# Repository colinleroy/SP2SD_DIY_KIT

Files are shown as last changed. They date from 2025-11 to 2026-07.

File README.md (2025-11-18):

# Why this fork?

I recently bought an SPIISD v2 kit so that I could have a "hard drive" on my Apple //c.
My use-case is to be able to save documents, photos, programs to a large storage, because
floppies are... small.

Upon testing, I was disappointed to see that the SPIISD v2 works great, in conjunction with
ROM4x, when we boot the Apple //c from Smartport using the ROM4x menu, but that the drive
was "invisible" when booting from the internal floppy disk drive.

I was told this was a limitation of the Apple //c firmware, but could not believe it, as
it was documented nowhere on Internet, and people back in the day would have had a hard time
booting from an external hard disk drive without any means to initialize it.

This is when the second disappointment happened: I wanted to investigate the problem, but when
I bought the SPIISD v2, I missed the part in the documentation that says that the v2 firmware
is closed-source. I doubt the legality of this, given that it seems heavily based on the v1.17
firmware which is MIT-licensed, but that is not my main problem so far, as I so far had no
copyright on v1.17. I was mostly annoyed that I couldn't debug anything further than looking
at serial logs.

I traced the PCB connections from the IDC-20 Smartport connector to the Nano, and the ones
from the SD card module to the Nano, ignored the four buttons and the screen, and compared
those to the gerber files for the v1 board (those are [here](SPSD_DIY_NANO_GERBER)).
All connections matching, I flashed the v1.17 firmware on my v2 board, and started debugging.

So far, this repository fixes my problem: the SPIISD board was booting too slowly, and
missed the first Smartport RESET and ENABLE at cold boot, and so could not advertise its
existence to the Apple //c.

I solved it by reflashing the firmware using an AVR ISP mkII programmer, which bypasses the
Arduino's bootloader. As this was not enough, I defer slow inits to after having replied to the
computer.

# I have an official SPIISD and the same problem, how do I fix it

If you're here because you want your Apple IIc to see your SPIISD (v1 or v2) on cold boot,
here are your options:

- Hit Ctrl-Open-Apple-Reset one second after cold booting. This re-resets the Smartport bus,
but this time the SPIISD is booted.
- Power your SPIISD via an USB adapter, so that it's on before the //c
- Flash this firmware to your board, using a programmer instead of the USB connection, to
fix the root of the problem.

*Warning*: If you flash this firmware on an SPIISD v2 board, you will lose the screen and
buttons functionalities. If you flash this firmware on a v1 board, you will lose the "Eject"
button that is used to switch the SPIISD's bootable image.

In any case, backup your original firmware, using (via USB connection to the nano):
```
avrdude -c arduino -P /dev/ttyUSB0 -b 115200 -p m328p -U flash:r:SPIISD.orig.hex
```

If needed, you can restore it by first using the arduino IDE to reflash the bootloader:
- Tools / Board : Arduino Nano
- Tools / Processor : ATmega328P
- Tools / Programmer: AVR ISP mkII (or whatever your programmer is)
- Tools : Burn bootloader

Then reflash the firmware using your backup:
```
avrdude -c arduino -P /dev/ttyUSB0 -b 115200 -p m328p -U flash:w:SPIISD.orig.hex
```

# Directions for this project

I am not yet sure what I want to do with this project. I would like to have my
firmware conform to my needs (for example, I need only one or two partitions, and
I dislike seeing S2D1 and S2D2 when I won't use them). I would also like it to
be a good, solid Smartport hard drive implementation that would benefit the
community at large: while it is easy to find mass storage solutions for the
slotted Apple IIs, there are far less options to the //c, and as far as I know,
only one - the out-of-stock SPIISD v1 - is open-source.

So, if people are interested in such a project, I'm in. I am bad at hardware,
and while I can wire shit to the correct pins to make prototypes, I have zero
experience at making PCBs and each time I try to learn it's a nightmare. I'm
also bad at 3D printing and couldn't design and print an enclosure. But I'm
quite good at software.

So far, only huge nerds can use this firmware: it requires competency in Arduino
flashing *and* in what to do to transform gerber files into PCBs: the v1 board
is out of stock at Kero Mac Mods store, and the PCB is licensed under the CC-BY-NC-SA,
which prohibits others to step up, have some built and sell them to the community.
(Or, you could by a v2 board and use this firmware. Still, it's not as easy as
it should).

So what I would love to is to design a new PCB, MIT-licensed too, so that anyone
interested could build and sell them. Probably not me, I don't want to turn my
hobby into work.

Then I would like to fix/add features, maybe:
- fix the Eject button so that one can rotate their bootable image
- a jumper block to select 1, 2 or 4 partitions possible
- a clean-room implementation of a basic image selection UI

# SPIISD DIY KIT

<br>

# What is SPIISD ?
It is based on an open source project called SmartPortSD. 
Created by Australian genius [Robert Justice](https://web.archive.org/web/20230222233834/http://www.users.on.net/~rjustice/SmartportCFA/SmartportCFA.htm), SmartPortCFA was ported to Arduino hardware by Italian programmer genius [Andrea Ottaviani](https://github.com/aotta?fbclid=IwAR0_7cMKVhMVrHznB9bIub9ZmrmBlwAM3p6-_CQd0JFW1o736nUNZHyuTdw).  to porting to Arduino hardware. It was improved upon by [Katherine Stark](https://gitlab.com/nyankat/smartportsd) of Canada. She made available its ability to access four ProDOS-formatted 32MB PO files stored on a FAT32-formatted SD card. When she did this successfully, many wanted to build it.

*Got permission from the three geniuses I introduced earlier.<BR><BR>

We differentiated it with a name to distinguish it from other SmartportSD hardware (including unlicensed ones).<BR><BR>

<BR>
More details here (My Blog):
https://ameblo.jp/keroxiee1016/entry-12819341808.html

## Flashing Arduino Nano

Oct 15th, 2024: SmartportSD program has been updated to Ver.1.17, version 1.17 has been thoroughly tested with "SPIISD" hardware and has confirmed good performance. Fixed a problem with the Apple IIcPlus, and improved versatility with slower SD cards. Usage is the same as V.1.16.

May 8th, 2024: SmartportSD program has been updated to Ver.1.16 by Wing Yeung from [MFA2 work shop](http://www.mfa2lab.com). version 1.16 has been thoroughly tested with "SPIISD" hardware and has confirmed good performance. This same 1.16 program can work with both "SPIISD DIY KIT" and "SPIISD MINI". *We have not verified SmartportSD compatible devices from other manufacturers. I think they work well if they keep the same schematics.<BR>

- By placing "config.txt" at the root of the SD card, you can place various files without renaming them.<BR>
- Write 4x file names in "config.txt". SPIISD will only read files with that filename.
In addition to ".po", ".hdv" and ".2mg" can be used as extensions.<BR>
- Of course, you can put an unlimited number of images in the root of the SD card, but only the config.txt file will be read.<BR>
- If you do not place config.txt, you can also place four files from PART1.po as before.<BR>

You can flash your Arduino Nano via ArduinoIDE. Please download and use firmware of ["SmartportSD-1.17" folder](SmartportSD-1.17). If a new folder is created when using the Arduino IDE, please re-insert all the contents of this "SmartportSD-1.17" folder into the new folder. *The name of the ".ino" file should always be the same as the parent folder, so there is usually no problem if you use it as is.<BR>
<BR>
The Nano board you should choose is MEGA328P. Please do not buy MEGA168P as it has 38% insufficient capacity and cannot be flashed.<BR>
<BR>
The Arduino IDE settings are as follows,<BR>
Board: "Arduino Nano"<BR>
Processor: "ATmega328P(Old Bootloader)"<BR>
Port: Number of USB port connected to Arduino Nano *In your PC<BR>
Programmer: "AVRISP mkII"<BR>

## Assemble
Uploaded on Sep 24, assembly instructions can be found [here](SP2SD_DIY_INST.pdf), You can see which parts should be attached where by looking at our [BOM](SP2SD_NANO_DIY_BOM.csv). 
<BR>

<BR>
The IDC20 connector can be oriented in various ways depending on how you use it, When installing the male IDC20pin connector, be sure to make sure that the part is on the top side. When stacking two PCBs, make sure the hole and ▼ are in the same position. In that case, match the IDC20pin male and female connectors or connect them with a 2X10 pin header.<BR><BR>
日本語の組み立て説明書は[こちら](SP2SD_DIY_INST_JPN.pdf)から

## DB19 male connector

You can 3D print the base material and pull out the pins from a [DB25 male connector](https://www.amazon.com/PC-Accessories-Connectors-Connector-25-PACK/dp/B073KR622F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) and insert them, or purchase new pins from [AliExpress](https://www.aliexpress.com/item/1005002617586407.html?spm=a2g0o.order_list.order_list_main.16.55d11802jCHaOW). We have omitted unnecessary pins to make it simple for you to create. I will give out free .STL files that can be 3D printed. <BR><BR> DB19 connector file is [this](KEROS_DB19_V1.zip).

## 3D printed shell case

Our awesome friend [Mr Lurch](https://www.youtube.com/channel/UCMQ28v823w6p1ZnyiZDVwUg) completed the shell case design. This can be used by connecting boards A and B with pin headers without using cables.<BR><BR>
 [Here](https://www.thingiverse.com/thing:6235981) is the case stl files for integrated.<BR>
 [Here](https://www.thingiverse.com/thing:6248598) is the case stl files for cable connection.




## Supported Apple II computers

<BR>


<BR><BR>
- Apple IIgs　*Even you set the startup slot to #5 and remove other bootable devices the startup timing does not match, try the shortcut key "Open Apple" + "Control" + "Reset" to reboot. If you are new to IIgs, make sure to release key "Open Apple"　 last and it will reboot easily.<BR>
- Apple IIc, IIc Plus *In the case of IIc, Smartport cannot be used as is with older ROM 255, so a ROM upgrade is required. See the chapter bellow
- Apple IIe, IIe Enhanced, IIe Platinum, works well with Grappler Minus card (1) with SoftSP diy ROM V2, V3 and V6-a. It works into the #5 slot and use it via the DiskII card in the #6 slot. In other words, it is a card that connects SmartPort with two cards.<BR>*You can also use it via "Liron" card, BMOW also has a highly functional card called "Yellowstone", which can also be used. <BR>
- Apple II Plus, works well with GrapplerMinus card with SoftSP diy ROM V2, V3 and V6-a.<BR>

(1) We developed the [Grappler Minus card](https://github.com/kerokero5150/GrapplerMinus/blob/main/README.md), which overcomes timing issues. This is also open source and anyone can create it, but it is not allowed to be sold. It is also available for purchase at our store. <BR><BR>
If you use SoftSP with the Genuine "Grappler Plus" card, the functionality of SoftSP DIY will be limited due to the unnecessary circuitry of the printer interface. Specifically, it only works with Apple IIe, and only V2 and V3 ROMs can be used.

## Usage
<BR>
Use a FAT32(16) formatted MicroSD card. Most of the MicroSD cards currently on sale can be used as is.
Extension .po files can be used.<BR><BR>

### Usage V.1.17(1.16)
New firmware allows the use of three file extensions: ".po", ".hdv", ".2mg", each files with a maximum size of 32MB.
As we have upgraded to V.1.17(1.16), the new method for setting up the SD card is described below. From v1.16 onwards, if "config.txt" is not placed in the root, it will be automatically recognized and converted to the old method. Please refer to “2, Old method” when "config.txt" is not placed.＜BR>
Place "config.txt" in the root of the SD card, this is a standard text document, which can be created using any text editors. This is the table of contents for loading the specified file into the Apple II. The contents of "config.txt" must have a file name written on each line, and you can specify up to four files to launch. You can add as many files as you like up to the capacity of the SD card. However, SPIISD can only read the four files with the names written in config.txt. The file extensions are either ".po", ".hdv", or ".2mg". SPIISD will read from the first file written (on the first line). Please keep in mind that the file specification must always be 4 lines for 4files.

### Usage up to V.1.15<BR>
The Apple ProDOS disk image that can be used for SPIISD is a .PO file with a maximum size of 32MB. Place this file at the root of your micro SD card. Up to 4 files can be recognized. The first file name should be “PART1.PO”. As you can imagine, there can place four files, so from the second file on, name the files with regularity, such as "PART2.PO", "PART3.PO", and "PART4.PO".<BR>
For disk images with the .hdv extension, the catalog structure is the same, so you should be able to use them by simply renaming the file to .po. An APP called CiderPressV4 can convert other file extensions to .po.<BR><BR>
I think the most popular way to use SPIISD on the IIc is to use TotalReplay, a collection of old appleII games. <BR>
The IIgs supports GSOS. In this case, you can check all four files at the same time on the OS's finder. If you only have a IIgs, the SPIISD is the device with the best value for money.<BR><BR>
*If you change the extension from .hdv to .po and it doesn't work, you can use CiderPress to convert it to a .PO file. CiderPressV4 can be done on Windows 7 and up. *For Win98/ME/2K/XP there is an older version.<BR>
<BR>
CiderPress V4:<BR>(https://a2ciderpress.com)<BR><BR>
TotalReplay:<BR>(https://archive.org/details/TotalReplay)<BR><BR>

## To use Apple IIc's smart port
For Apple IIc, Smartport will not be enabled if ROM 255 is installed(Probably ROM0 as well). To check the ROM of your IIc, run the following program from the Basic prompt.
  PRINT PEEK (64447)
If the output number is "255", the ROM needs to be replaced. The ROM versions that Smartport can use are "3", "4" and ROM"4x". For these numbers, ROM replacement is not necessary.

The replaced ROMs are available [here](https://mirrors.apple2.org.za/Apple%20II%20Documentation%20Project/Computers/Apple%20II/Apple%20IIc/ROM%20Images/).
There is also the useful hacked [ROM4X](https://github.com/mgcaret/rom4x). This is a fairly new ROM updated in 2018.<BR><BR>

My recommendation is ROM4X.<BR>

If you want to swap the ROM from 255 to another ROM, you need to change the solder jumpers "W1" and "W2". 
255 is 16KB while other ROMs are 32KB. Enable 32KB by changing Pin27, which is A14, from pull-down to pull-up. 
See below for solder jumper locations. [External site](https://www.apple2faq.com/apple2faq/apple-iic-rom-upgrade/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)

## To get the SPIISD PCB

You can use [SPSD_DIY_NANO_GERBER.zip](SPSD_DIY_NANO_GERBER.zip)  and uploading it to JLCPCB or PCBWAY as it is.

<BR>


The [SPIISD DIY kit](https://en.infinityproducts.co.jp/product-page/sp2sd-diykit-bare-pcb-board-a-b) comes complete with all parts, sold in our [store](https://en.infinityproducts.co.jp/shop-1). [SPIISD mini](https://en.infinityproducts.co.jp/product-page/spiisd-mini-for-iic-iicplus-iigs) is a compact hardware with fixed db19. It does not require assembly, so it is recommended for those who want to use it immediately, and for those who want a sense of unity with Apple IIc.

## Licenses

SmartportSD software licenses are listed [here](SMARTPORTSD_LICENSE.md) under the MIT license.
Ⓒ2023 Katherine Stark, Robert Justice, Andrea Ottaviani. All rights reserved.

This SPIISD hardware is licensed under a
[Creative Commons Attribution-ShareAlike 4.0 International License](https://creativecommons.org/licenses/by-nc-sa/4.0/).
Ⓒ 2023 Kay Koba, Kero's mac Mods, All rights reserved.


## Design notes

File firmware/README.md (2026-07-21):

# Programming the Arduino Nano with BurgerDisk's firmware

In order for the Arduino Nano to boot fast enough to answer an Apple //c booting
from its internal floppy, the Nano **has** to be programmed using an AVR ISP
programmer. I use an [STK500 AVR ISP programmer](https://aliexpress.com/item/1005006205386137.html).

Open a terminal, and change to this `firmware/` directory.

## Arduino IDE installation
Install the Arduino IDE, for example on a Debian-based Linux distribution:
```
sudo apt install arduino
```

Start it:
```
arduino .
```

## Arduino IDE configuration
The Arduino IDE Tools menu.

In `Tools` menu, `Programmer` submenu, select your programmer.

You can then either continue using the Arduino IDE interactively:
- In `Tools` menu, `Board` submenu, select `Arduino Nano`.
- In `Tools` menu, `Processor` submenu, select `Atmega328p`.
- In `Sketch` menu, `Include Library` submenu, select `Manage Libraries...`.
  Manage Libraries menu item.
- Search for `SdFat` by Bill Greiman, scroll to it, and install version 2.3.0 (Screenshot shows 2.1.2, but choose 2.3.0).
  SdFat installation

Or, you can quit the Arduino IDE, and in your terminal, run:
```
make setup
```

## Flashing the firmware
**Make sure that the Nano is out of the BurgerDisk PCB, or that the BurgerDisk
is disconnected from the Apple II, even if the Apple II is turned off, before connecting the programmer. NEVER connect the programmer when the BurgerDisk is
connected to the Apple II.**

Connect your Arduino Nano to the programmer's 6-pin connector. The red
wire of the connector must be towards the Nano's `VIN` pin.
The Arduino Nano, connected to the programmer

For the Dominodisk, the procedure is the same. Open the Dominodisk enclosure to
locate the programming header, and connect it:
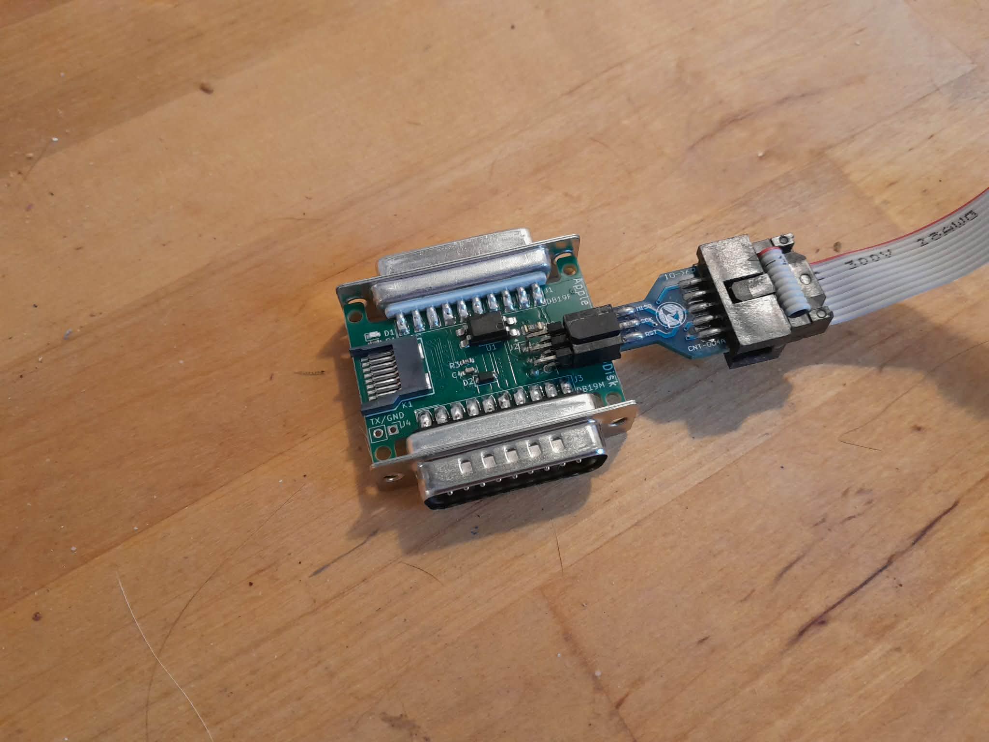
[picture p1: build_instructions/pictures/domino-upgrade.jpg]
The Dominodisk, connected to the programmer


Two options here too:
- From the Arduino IDE, `Sketch` menu, choose `Upload using programmer`. Wait
  until the "Done uploading" message.
  Upload using programmer menu item
- From the command line, run `make fuse && make upload`. Wait for the upload to be done.

Disconnect the programmer, and you're set.

## Debugging
If you need to debug the firmware, you can connect its UART pins to an [UART/USB
converter](https://aliexpress.com/item/1005008293602159.html). Wire the
BurgerDisk's UART `GND` pin to the USB converter `GND` pin, and the BurgerDisk's
UART `TX` pin to the USB converter's `RX` pin.

Plug the USB converter in your computer, check its device file (using `dmesg`
for example), then run:
```
minicom -D /dev/ttyUSB0 -8 -b230400
```

Connect the BurgerDisk to the Apple II, and boot the Apple II. Log messages
should be visible in Minicom. Remember: **never have the programmer connected
while the PCB is connected to an Apple II!**

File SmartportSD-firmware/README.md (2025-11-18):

# SmartportSD FAT version 1.17

This is an enhancement of the [SmartportCFA/SmartportSD](http://www.users.on.net/~rjustice/SmartportCFA/SmartportCFA.htm) project by Robert Justice and Andrea Ottaviani. Instead of relying on four raw disk images written sequentially to an SD card, this version allows you to have up to four files on a FAT or FAT32 formatted SD card instead.

version 1.17: Improved version by Wing Yeung from [MFA2 work shop](http://www.mfa2lab.com). version 1.16 has been thoroughly tested with "SPIISD" hardware and has confirmed good performance.This same 1.16 program can work with both "SPIISD DIY KIT" and "SPIISD MINI". V1.17 adds support for IIcPlus. Memory allocation has been changed to dynamic allocation.

*We have not verified SmartportSD compatible devices from other manufacturers. I think they work well if they keep the same schematics.

# Usage

## Get the programs

Download or git clone the source to this project. Copy and use the "SmartportSD-firmware" folder as is.

## Get the dependencies

Download the 2.1.2 version of the [SdFat Arduino library](https://github.com/greiman/SdFat/) and install it in your Arduino libraries folder (that location is system-dependent so you'll have to figure out where it is for you, sorry).

## Compile and upload the code to the Arduino

## Wire up the Arduino

Follow the instructions on [Robert's page](http://www.users.on.net/~rjustice/SmartportCFA/SmartportSD.htm) for the wiring diagram.

### WARNING

Don't connect the Arduino USB and the +5V power to the Apple computer at the same time! Doing so could lead to a situation where +5V is backfeeding into the Apple from the Arduino, which is bad.

If you plan on doing development work on this, or just want to watch the Arduino serial console for error messages, disconnect the +5V connection between the Apple II and the Arduino and power it only via the USB port.

If you use the v1 or v2 PCBs from Kero Mac Mods, there is a diode preventing this
from happening, so it's possible in this case.

#### Technical details
The Apple needs more than the 500mA your modern computer's USB power supply can provide to boot up, plus it needs some other voltages as well. You could end up burning out your Arduino, your USB port, your Apple, or all of the above! (The most likely thing to happen is the USB port might shut off, or the Arduino will get hot and annoyed, though).

## Place images on the SD card

You can place unlimited images in the root or subfolders of the SD card. However, only the four files specified in config.txt can be mounted.
By placing "config.txt" at the root of the SD card, you can place various files without renaming them.
Write 4x file names in "config.txt". SPIISD will only read files with that filename.
In addition to ".po", ".hdv" and ".2mg" can be used as extensions.
If config.txt is not in the root, Name your images PART1.PO through PART4.PO. If you don't have four images that's OK, the missing ones will be skipped.

### NOTE

Images must be unadorned ProDOS-order images. They don't have to be ProDOS file systems though - ISO9660, DOS 3.3 and HFS should work (although they are currently untested).

## Change boot  order, if you want

The eject button, if you have it wired up, will work the same way as it does in Robert's version of the code. Hold the button down while power cycling the Apple (or pressing the Arduino reset button if the USB connection is supplying power) to choose the next of the four images as the new startup disk. Then power cycle (or reset) the Arduino again without the button held down to get ready for the next boot.

### WARNING

Make sure you have a pulldown resistor to ground on the eject button pin (Analog pin 3). If you don't, the Arduino will assume the button is always being held down and keep changing the boot device and never start its normal operation. Ask me how much debugging trouble this caused me!

## Boot the machine!

That's it, turn on the machine and it should boot from PART1.PO!

## BUGS

- The combination of this device, a ROM 03 IIgs, and a CFFA3000 card seems to  prevent booting from this device. If you have this setup, please test it and report back to me.
- The code for switching boot partitions is probably going to fail if files get renamed so that a previously present boot partition goes away.

Please report bugs or comment on the above via the GitLab issues page for the project.

April 27, 2024, Ver 1.16 edited by Kay Koba, Kero's Mac Mods

(C) SmartportSD Project

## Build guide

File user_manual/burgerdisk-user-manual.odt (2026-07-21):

BurgerDisk/DominoDisk Smartport Hard Disk for Apple II

User manual

Version 2.5

April 2026

colin@colino.net – https://www.colino.net/

# Index of Figures

Figure 1: Inserting the MicroSD card 5

Figure 2: Example daisy-chain 6

# Index of Tables

Table 1: Example config.txt 4

# Introduction

BurgerDisk and DominoDisk are Smartport hard disks, with storage backed on a microSD card, for the Apple II line of computers running ProDOS.

Both devices share the same firmware and the same features, so this user manual applies equally to both devices.

It is compatible with the Smartport-enabled Apple II models:

- The Apple //c (apart from the ROM255 version, which can be upgraded)
- The Apple IIgs
- Slotted Apple II computers with a Smartport controller:
  - DiskII controller + a SoftSP card, or
  - Liron card, or
  - Liron Reborn card

It is daisy-chainable, which lets you use other storage devices with it.

# BurgerDisk storage configuration

## Presenting disk images to the computer

Different image formats are supported:

- .po (in ProDOS-ordered format)
- .2mg (in ProDOS-ordered format)
- .dsk (in ProDOS or DOS3.3-ordered format, but of ProDOS volumes)
- .hdv

These images can be either 140KB, 400KB, 800KB, or an arbitrary number of blocks up to 32MB (65535 blocks).

The BurgerDisk does not support .woz, .nib, .edf, .do images.

BurgerDisk uses these disk images to present to ProDOS. They are stored as files on the MicroSD card, formatted as FAT.

By default, the firmware will search for four files: PART1.po, PART2.po, PART3.po, PART4.po, and present them if they exist.

You can also put images with arbitrary names, and reference at most four of them in the config.txt file at the root of the MicroSD’s filesystem.

Table 1: Example config.txt

A2DeskTop-1.5-en_800k.2mg

Total Replay v5.2.hdv

Documents.po

Your Apple II can boot from any slot, but only from the first device in any slot. For the BurgerDisk, this means you can boot from the BurgerDisk’s first volume if the device is first in the daisy-chain. Booting from another partition requires modifying their order in config.txt.

Afterwards, you can insert the MicroSD card in its slot (face up, connector down), connect your device to your Apple II, and boot it.

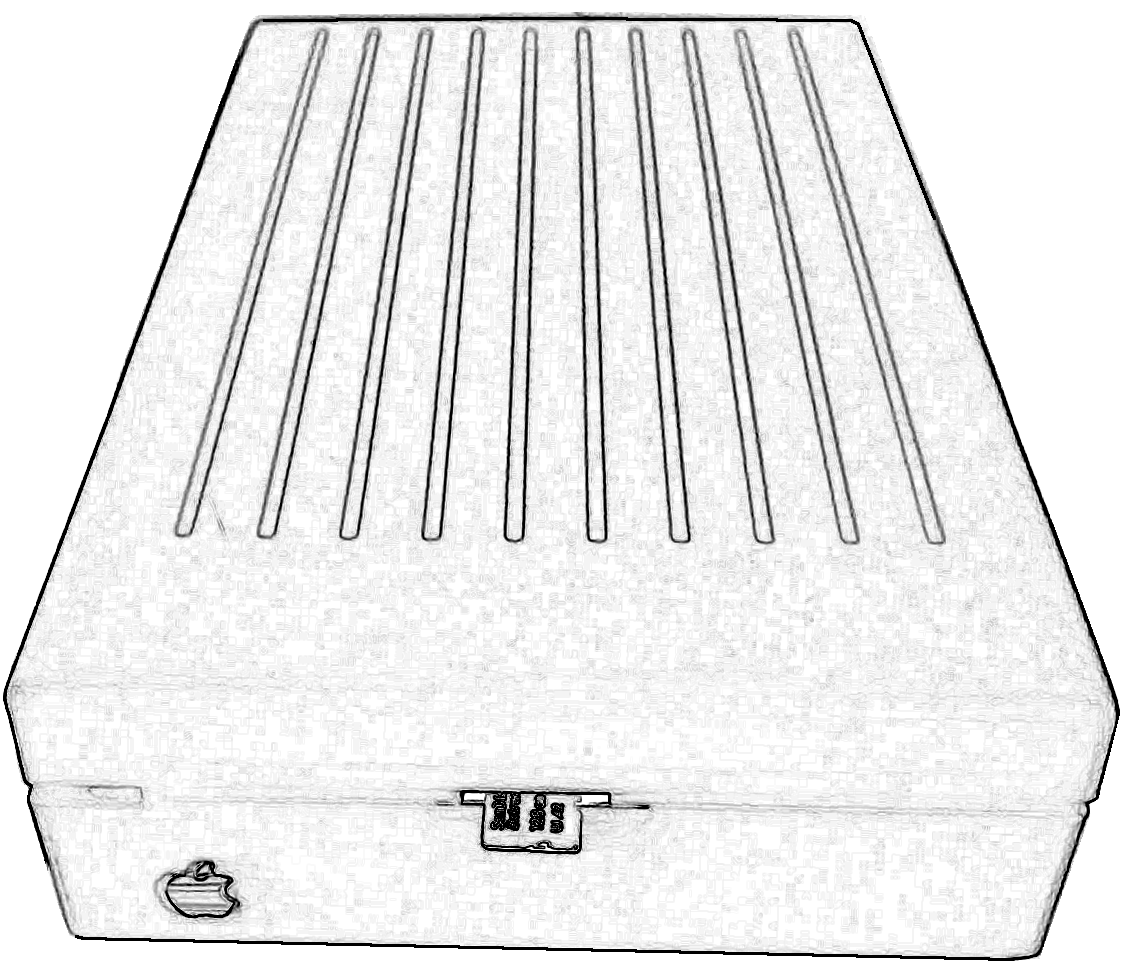
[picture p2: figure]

Figure 1: Inserting the MicroSD card

Push the card until it clicks in place. Push it again to remove it.

## Debugging and options

debug (default 0): If you would like to work on the BurgerDisk firmware, enabling debug messages on its serial port will be useful. You can do that by adding debug=1 in an options.txt file at the root of the SD card.

force_next_smartport (default 1): By default, BurgerDisk lies to the controller, telling it there are more Smartport devices after it. This makes chaining an SPIISD (or other devices that do not correctly advertise themselves as Smartport devices) possible. It has no adverse effects, but this can be disabled using force_next_smartport=0 in the options.txt file.

# BurgerDisk installation

To connect the BurgerDisk to your Apple II, you can either plug it directly to the computer, or to another device, in what is called a Daisy Chain. This allows you to have multiple storage devices connected to your computer. Daisy chains have rules about devices ordering:

- First “dumb” 3.5” floppy drives, like the Apple 3.5 Drive (A9M0106) (only on the IIgs or //c+)

- then Smartport devices, like the Unidisk 3.5 (A2M2053) or the BurgerDisk

- followed by 5.25” floppy drives (except on Liron cards, which do not handle 5.25” drives at all)

In this example, the Apple II will be able to boot from the Unidisk 3.5”. To boot from the BurgerDisk’s first partition, invert the Unidisk 3.5” and BurgerDisk, so that the BurgerDisk is connected to the computer, the Unidisk connected to the BurgerDisk, and the Disk //c connected to the Unidisk.

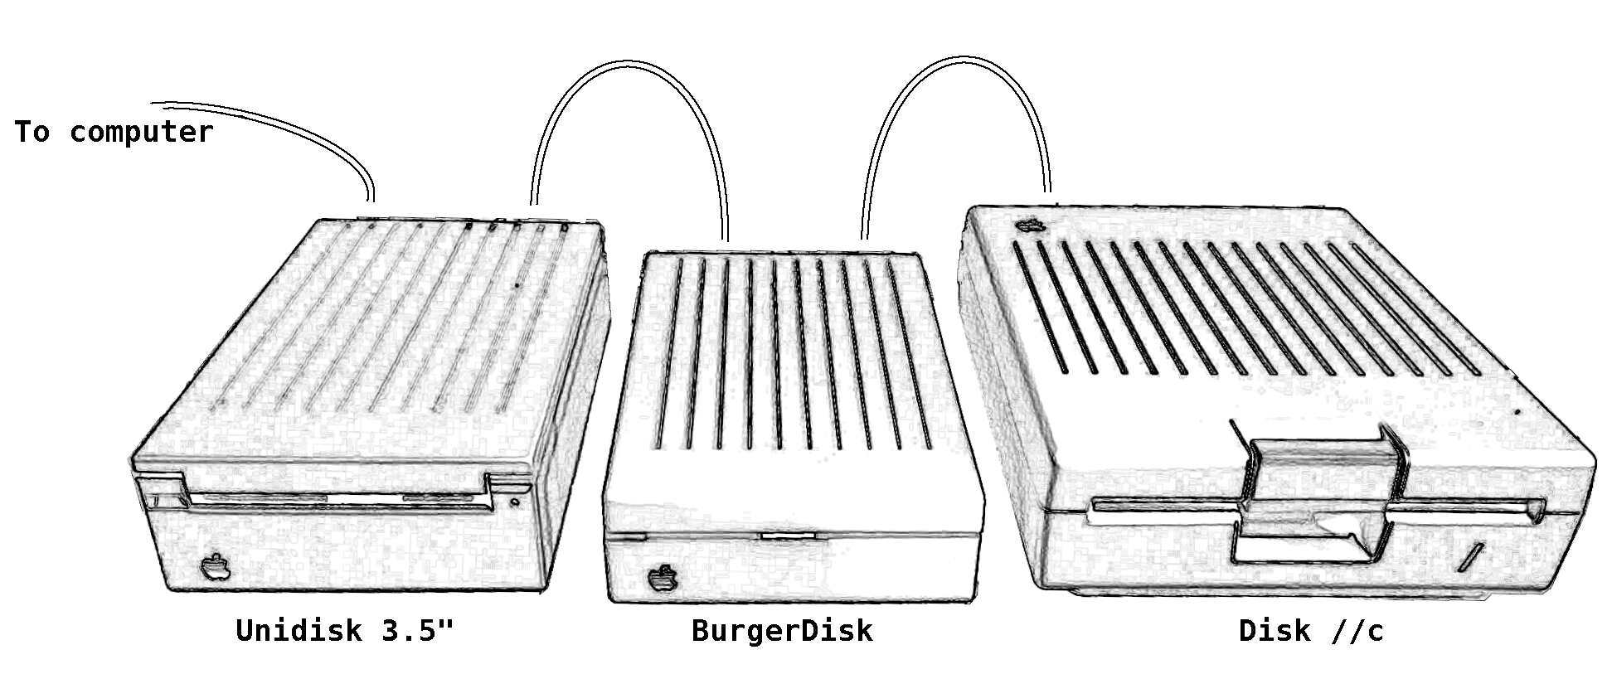
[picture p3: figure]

Figure 2: Example daisy-chain

# Booting the computer

The Apple II can boot from the first device in a given slot. Smartport devices are usually in slot #5, and 5.25” drives in slot #6.

If you want to boot your Apple II from the BurgerDisk, use a bootable image, like A2Desktop, as first image; and connect the BurgerDisk first to the computer.

Note: this means that you cannot directly boot from the BurgerDisk if an Apple 3.5” drive (A9M0106) is present in your chain, even if no floppy is inserted into it; because the A9M0106 drive has to be connected first.

# Troubleshooting

## Serial debug output

If you are investigating a problem or experimenting with your own modifications of the firmware, you might want to enable debug output on the Arduino’s serial port.

This can be enabled with a debug=1 line in options.txt.

Afterwards, you can open the enclosure, locate the UART port, and connect an UART to USB adapter to it. Connect the UART’s GND to the adapter’s GND, and the UART’s TX to the adapter’s RX.

## Blinking LED, no image mounted

If after booting the Apple II, a small delay happens, followed by the BurgerDisk’s LED blinking 4 times per second, and none of its volumes are visible by ProDOS, this means that the MicroSD card initialization failed, or that zero valid images were found on the card. Verify its presence and contents.

## Compatibility

So far, the BurgerDisk has been tested on:

- Apple //c ROM3, model A2S4000
- Apple //c ROM4x, model A2S4100
- Apple IIgs, ROM01
- Apple IIe, Liron card
- Apple IIe, DiskII controller + SoftSP card

Various daisy chaining configurations have been tested:

- only the BurgerDisk on the Smartport bus
- Unidisk 3.5”, then BurgerDisk
- BurgerDisk, then Disk //c
- Unidisk 3.5”, then BurgerDisk, then Disk //c
- Unidisk 3.5”, then BurgerDisk, then another BurgerDisk, then Disk //c
- BurgerDisk, then Unidisk 3.5”, then Disk //c

In case of problems in a daisy chain, verify that your chain respects Apple’s rules, and that the chained devices are actually able to be chained.

Liron card notes: the Liron card is not able to drive a 5.25” drive.

SoftSP card notes: the SoftSP card is not able to drive a Unidisk 3.5” drive. It has annoying, but non-blocking issues with 5.25” drives.

Compatibility with the SPIISD, Fujinet, or other Smartport-based devices has not yet been tested.

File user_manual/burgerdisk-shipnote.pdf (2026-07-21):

## BurgerDisk Smartport Hard Disk for Apple II

## Quickstart

Thank you for getting a BurgerDisk! I hope you will like it.

The User Manual is available at https://www.colino.net/wordpress/wp-content/burgerdisk-usermanual.pdf (https://www.colino.net/wordpress/wp-content/burgerdisk-user-manual.pdf)

Here are the most relevant parts:
Insert a FAT-formatted microSD card in the slot, face up. The volumes presented to the Apple II must be named PART1.po to PART4.po, or be referenced in a config.txt file containing up to four lines with the filenames. For example:
A2Desktop.hdv
Total_Replay.hdv
ProDOS 2.4.3.po

Do not hotplug Apple II storage devices while the Apple II is powered on. Plug any “dumb” 3.5inch drive first, followed by the DominoDisk and Smartport devices, followed by 5.25” drives.

Your enclosure comes with a placeholder logo taped at the front. You can either glue it, or replace it with a real vintage Apple logo if you have one!
Have fun,
Colin
colin@colino.net

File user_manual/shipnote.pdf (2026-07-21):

## BurgerDisk Smartport Hard Disk for Apple II

## Quickstart

Thank you for getting a BurgerDisk! I hope you will like it.

Quick pointers to start using it:

The User Manual is available at https://www.colino.net/wordpress/wp-content/burgerdisk-user-manual.pdf (https://www.colino.net/wordpress/wp-content/burgerdisk-user-manual.pdf)

Assembly instructions are available at https://github.com/colinleroy/BurgerDisk/tree/main/build_ins tructions (https://github.com/colinleroy/BurgerDisk/tree/main/build_instructions)

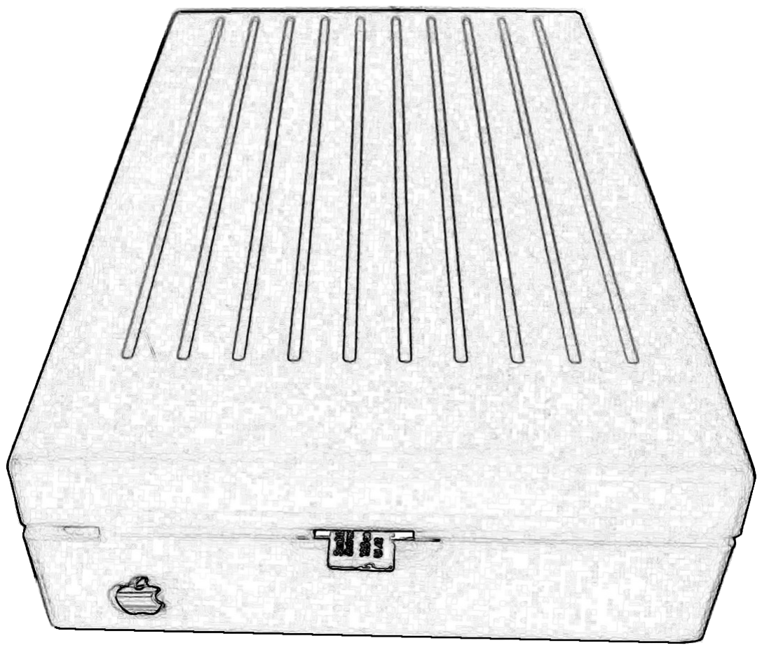
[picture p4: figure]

Your enclosure comes with a 3D-printed Apple logo taped to it. You can either glue it, or remove it and glue a real vintage Apple logo if you have one available.
Have fun!

Kit contents
Small components taped here

R2
150Ω

R1
330Ω

D1
removed

D2
1N4448

D3
1N5818

R4
10kΩ

R5
1kΩ

R3
470Ω

E

r

r

a

t

a: D1 w

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
d. In the box, for the PCB
- One BurgerDisk PCB
- One adapter PCB
- One Arduino Nano
- One MicroSD module
- One pair of DB19 connectors
- One pair of IDC20 connectors
- One pair of 15-pin sockets
- One LED
- One PC817 optocoupler
- Two 2-pin headers
- One 6-pin header
- One 6-pin cable
- One 2-pin cable
- One IDC20 cable
- 2 M2x8mm screws

In the box, for the enclosure
- The enclosure itself
- The adapter’s enclosure
- One LED diffuser
- One white Apple logo
- Two M2x12mm screws
- Four M3x20mm screws

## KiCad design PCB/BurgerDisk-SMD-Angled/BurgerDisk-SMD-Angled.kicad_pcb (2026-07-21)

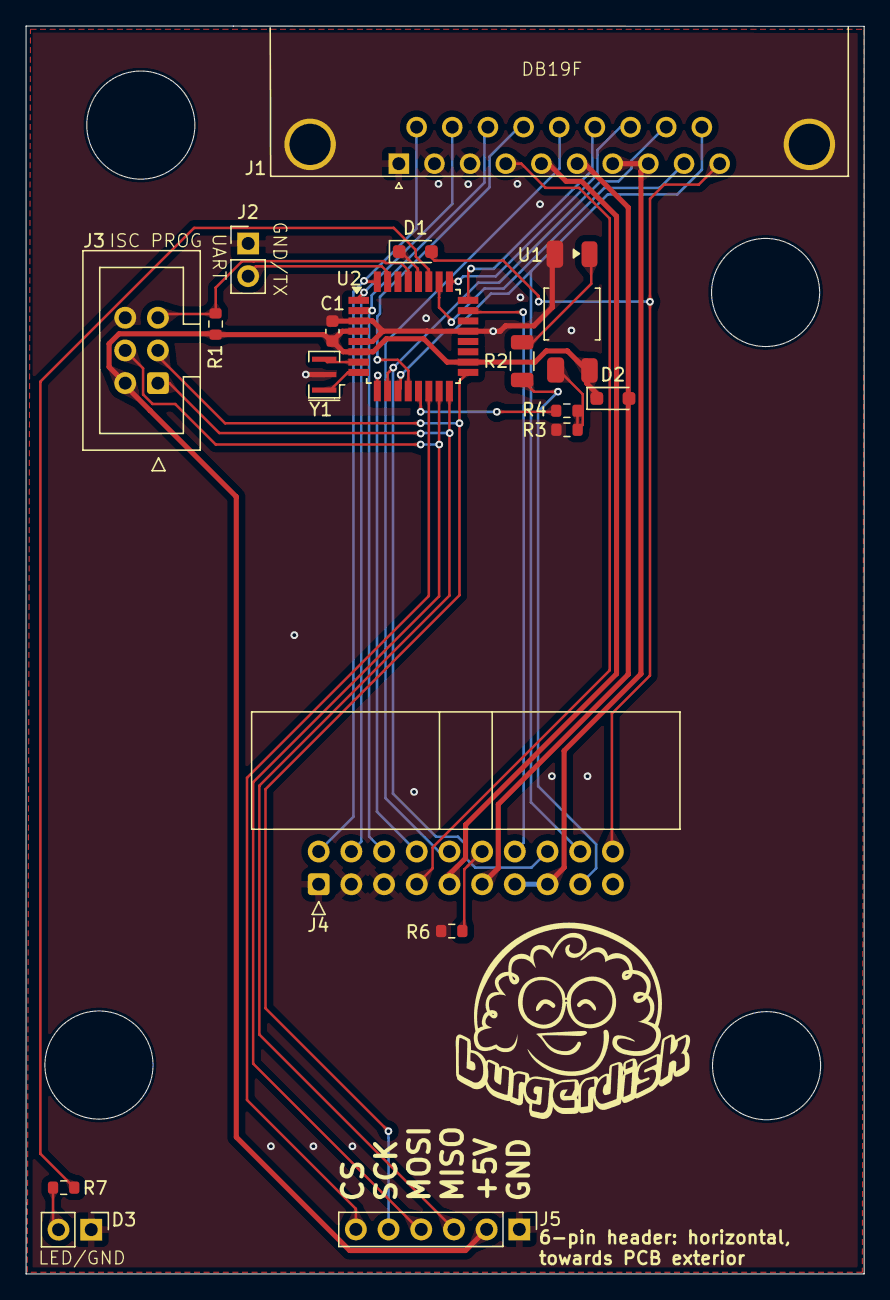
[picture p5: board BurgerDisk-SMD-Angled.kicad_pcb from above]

Board: 2 copper layers, 65.1 x 96.9 mm, 18 parts (0 on the bottom side), 35 nets.

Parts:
C1: 100n; C_0603_1608Metric
D1: 1N4448WS; D_SOD-323_HandSoldering
D2: 1N5818WS; D_SOD-323_HandSoldering
D3: LED; PinHeader_1x02_P2.54mm_Vertical
J1: Daisy port out; DSUB-19_Female_Horizontal_MXS82009-8251-9246
J2: 2-pin header; PinHeader_1x02_P2.54mm_Vertical
J3: ICSP_ISP6; IDC-Header_2x03_P2.54mm_Vertical
J4: Daisy port in; IDC-Header_2x10_P2.54mm_Horizontal
J5: MicroSD module; PinHeader_1x06_P2.54mm_Vertical
R1: 10K; R_0603_1608Metric
R2: 470; R_1206_3216Metric
R3: 10k; R_0603_1608Metric
R4: 1k; R_0603_1608Metric
R6: 330; R_0603_1608Metric
R7: 150; R_0603_1608Metric
U1: PC817C-S; SOP-4_3.8x4.1mm_P2.54mm
U2: ATmega328P-AU; TQFP-32_7x7mm_P0.8mm
Y1: Resonator_GND2; Resonator_SMD_Murata_CSTxExxV-3Pin_3.0x1.1mm

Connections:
5V_apple2: D2.2 (A), J1.6, J4.11
5V_burgerDisk: C1.1, D2.1 (K), J3.2, J5.2, R1.1, U1.4, U2.4 (VCC), U2.6 (VCC), U2.18 (AVCC)
+12V: J1.7, J1.8, J4.13, J4.15
-12V: J1.5, J4.9
CS: J5.6, U2.14 (PB2)
DRV1_in: J4.14, U2.23 (PC0)
DRV1_out: J1.17, U2.25 (PC2)
DRV2_burgerDisk: R4.1, U2.13 (PB1)
DRV2_in: J4.17, R2.1
DRV2_out: J1.9, U2.26 (PC3)
EN3.5: J1.4, J4.7
GND: C1.2, D3.1 (K), J1.0 (GND), J1.1, J1.2, J1.3, J2.1, J3.6, J4.1, J4.3, J4.5, J5.1, R3.1, R6.1, U1.2, U2.3 (GND), U2.5 (GND), U2.21 (GND), Y1.2
HDSEL_in: J4.12, R6.2
HDSEL_out: J1.16, U2.24 (PC1)
LED: R7.2, U2.27 (PC4)
MISO: J3.1, J5.3, U2.16 (PB4)
MOSI: J3.4, J5.4, U2.15 (PB3)
unnamed: D3.2 (A), R7.1
unnamed: R2.2, U1.1
unnamed: R3.2, R4.2, U1.3
unnamed: U2.7 (XTAL1/PB6), Y1.3
unnamed: U2.8 (XTAL2/PB7), Y1.1
PH0: J1.11, J4.2, U2.32 (PD2)
PH1: J1.12, J4.4, U2.1 (PD3)
PH2: J1.13, J4.6, U2.2 (PD4)
PH3_in: J4.8, U2.9 (PD5)
PH3_out: J1.14, U2.12 (PB0)
RDDATA: J1.18, J4.16, U2.10 (PD6)
RESET: J3.5, R1.2, U2.29 (~RESET/PC6)
SCK: J3.3, J5.5, U2.17 (PB5)
TX: J2.2, U2.31 (PD1)
WRDATA: J1.19, J4.18, U2.11 (PD7)
WREQ: J1.15, J4.10
WRPROT_in: D1.1 (K), U2.28 (PC5)
WRPROT_out: D1.2 (A), J1.10, J4.20

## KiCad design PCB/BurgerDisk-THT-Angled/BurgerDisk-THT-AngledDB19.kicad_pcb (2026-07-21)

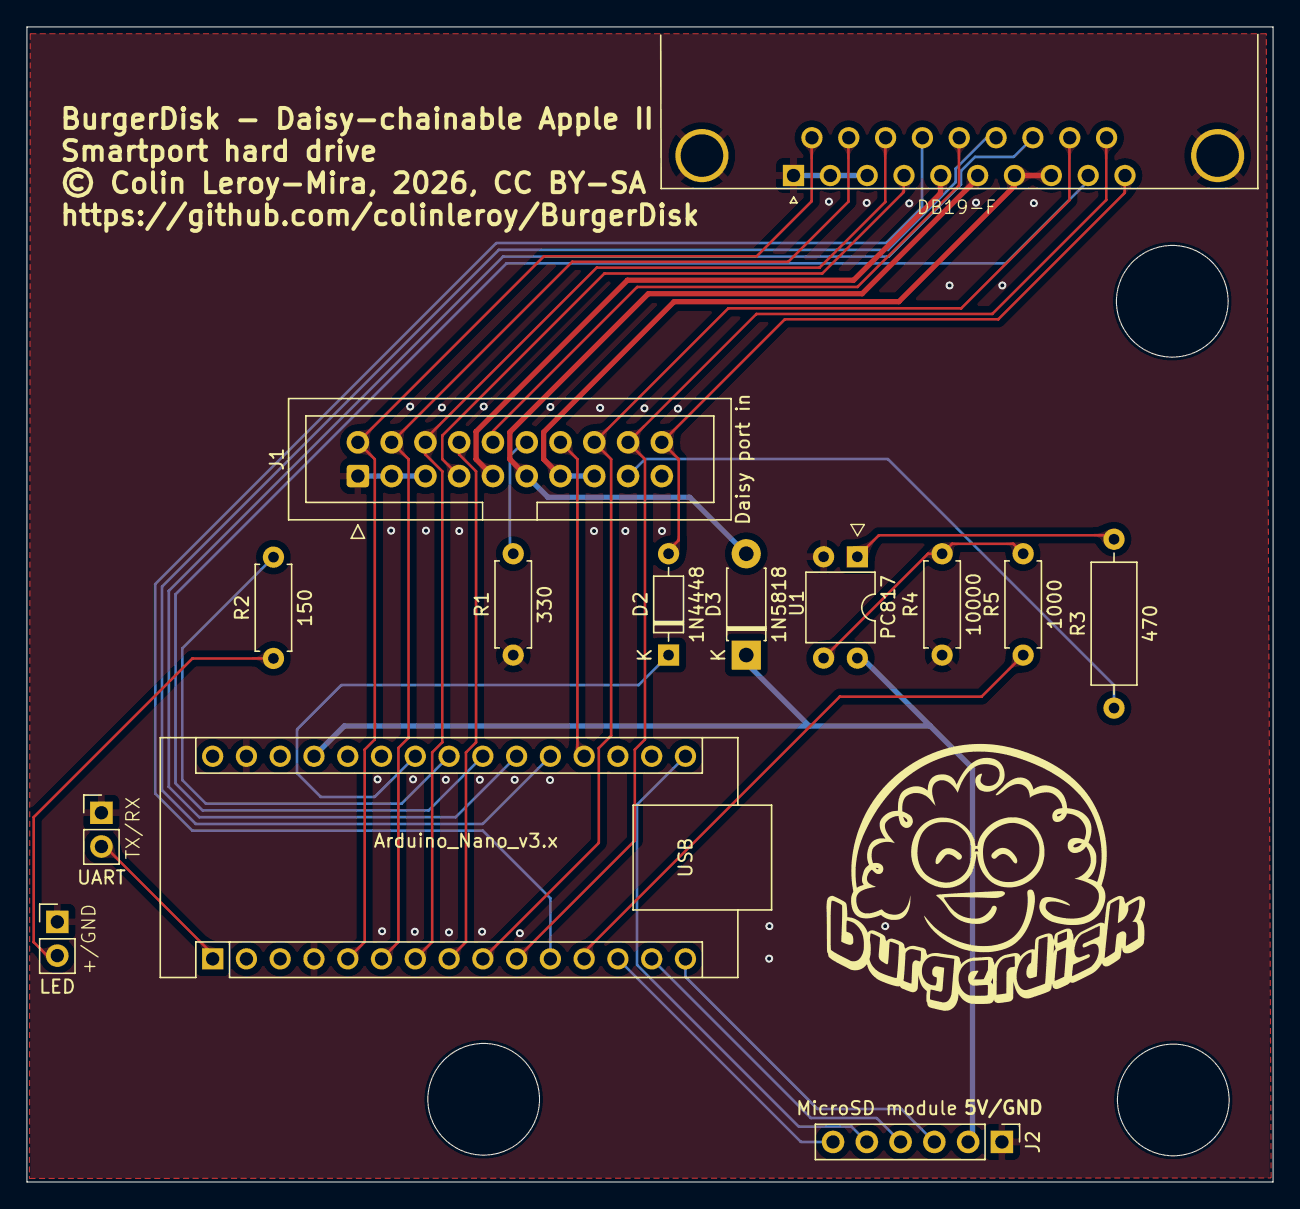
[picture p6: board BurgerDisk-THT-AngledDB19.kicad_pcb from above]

Board: 2 copper layers, 93.7 x 86.9 mm, 14 parts (0 on the bottom side), 32 nets.

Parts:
A1: Arduino_Nano_v3.x; Arduino_Nano
D2: 1N4448; D_DO-35_SOD27_P7.62mm_Horizontal
D3: 1N5818; D_DO-41_SOD81_P7.62mm_Horizontal
D4: LED; PinHeader_1x02_P2.54mm_Vertical
J1: Daisy port in; IDC-Header_2x10_P2.54mm_Vertical
J2: MicroSD module; PinHeader_1x06_P2.54mm_Vertical
J3: UART; PinHeader_1x02_P2.54mm_Vertical
J4: Daisy port out; DSUB-19_Female_Horizontal_MXS82009-8251-9246
R1: 330; R_Axial_DIN0207_L6.3mm_D2.5mm_P7.62mm_Horizontal
R2: 150; R_Axial_DIN0207_L6.3mm_D2.5mm_P7.62mm_Horizontal
R3: 470; R_Axial_DIN0309_L9.0mm_D3.2mm_P12.70mm_Horizontal
R4: 10000; R_Axial_DIN0207_L6.3mm_D2.5mm_P7.62mm_Horizontal
R5: 1000; R_Axial_DIN0207_L6.3mm_D2.5mm_P7.62mm_Horizontal
U1: PC817; DIP-4_W7.62mm

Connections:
5V_apple2: D3.2 (A), J1.11, J4.6
5V_burgerDisk: A1.27 (+5V), D3.1 (K), J2.2, U1.4
+12V: J1.13, J1.15, J4.7, J4.8
-12V: J1.9, J4.5
CS: A1.13 (D10), J2.6
DRV1_in: A1.19 (A0), J1.14
DRV1_out: A1.21 (A2), J4.17
DRV2_burgerDisk: A1.12 (D9), R5.1
DRV2_in: J1.17, R3.1
DRV2_out: A1.22 (A3), J4.9
EN3.5: J1.7, J4.4
GND: A1.4 (GND), A1.29 (GND), D4.1 (K), J1.1, J1.3, J1.5, J2.1, J3.1, J4.0, J4.1, J4.2, J4.3, R1.1, R4.1, U1.2
HDSEL_in: J1.12, R1.2
HDSEL_out: A1.20 (A1), J4.16
MISO: A1.15 (D12), J2.3
MOSI: A1.14 (D11), J2.4
unnamed: A1.23 (A4), R2.2
unnamed: D4.2 (A), R2.1
unnamed: R3.2, U1.1
unnamed: R4.2, R5.2, U1.3
PH0: A1.5 (D2), J1.2, J4.11
PH1: A1.6 (D3), J1.4, J4.12
PH2: A1.7 (D4), J1.6, J4.13
PH3_in: A1.8 (D5), J1.8
PH3_out: A1.11 (D8), J4.14
RDDATA_in: A1.9 (D6), J1.16, J4.18
SCK: A1.16 (D13), J2.5
TX: A1.1 (D1/TX), J3.2
WRDATA: A1.10 (D7), J1.18, J4.19
WREQ: J1.10, J4.15
WRPROT_in: A1.24 (A5), D2.1 (K)
WRPROT_out: D2.2 (A), J1.20, J4.10

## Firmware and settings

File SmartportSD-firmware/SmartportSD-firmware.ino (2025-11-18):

//*****************************************************************************
//
// Apple //c Smartport Compact Flash adapter
// Written by Robert Justice  email: rjustice(at)internode.on.net
// Ported to Arduino UNO with SD Card adapter by Andrea Ottaviani email: andrea.ottaviani.69(at)gmail.com
//
// 1.00 - basic read and write working for one partition
// 1.01 - add support for 4 partions, assume no other smartport devices on bus
// 1.02 - add correct handling of device ids, should work with other smartport devices
//        before this one in the drive chain.
// 1.03 - fixup smartort bus enable and reset handling, will now start ok with llc reset
// 1.04 - fixup rddata line handling so that it will work with internal 5.25 drive. Now if
//        there is a disk in the floppy drive, it will boot first. Otherwise it will boot
//        from the CF
// 1.05 - fix problem with internal disk being always write protected. Code was stuck in
//        receivepacket loop, so wrprot(ACK) was always 1. Added timeout support for
//        receivepacket function, so this now times out and goes back to the main loop for
//        another try.
// 1.1  - added support for being connected after unidisk 3.5. Need some more io pins to
//        support pass through, this is the next step.
//
// 1.12 - add eeprom storing of boot partition, cycling by eject button (PA3)
//
// 1.13 - Fixed an issue where the block number was calculated incorrectly, leading to
//        failed operations. Now Total Replay v3 works!
//
// 1.15 - Now uses FAT filesystem on the SD card instead of raw layout.
//
//
// 1.16 - Add support .hdv and .2mg (also .po), if add config.txt to the root of the sd card,
//        it will read any file name. images added to subfolders will also be loaded.
//        if not specified in config.txt, usage is the same as in versions up to 1.15.
//        improvement by Wing Yueng.
//
// 1.17 - Add support IIcPlus. Fixed memory allocation to dynamic allocation.
//
//
// Apple disk interface is connected as follows:
// wrprot = pa5 (ack) (output)
// ph0    = pd2 (req) (input)
// ph1    = pd3       (input)
// ph2    = pd4       (input)
// ph3    = pd5       (input)
// rddata = pd6       (output from avr)
// wrdata = pd7       (input to avr)
//
//led i/o = pa4  (for led on when i/o on boxed version)
//eject button = pa3  (for boxed version, cycle between boot partitions)
//
//
// Serial port was connected for debug purposes. Most of the prints have been commented out.
// I left these in and these can be uncommented as required for debugging. Sometimes the
// prints add to much delay, so you need to be carefull when adding these in.
//
// NOTE: This is uses the ata code from the fat/fat32/ata drivers written by
//       Angelo Bannack and Giordano Bruno Wolaniuk and ported to mega32 by Murray Horn.
//
//*****************************************************************************

//x #include <SPI.h>
#include "SdFat.h" // SDFat version 2.1.2
#include <avr/eeprom.h>

// Set USE_SDIO to zero for SPI card access.
// Deprecated maintly because I don't want to
// maintain two codepaths
// #define USE_SDIO 0

#include <avr/io.h>
#include <string.h>
#include <stdio.h>
#include <avr/pgmspace.h>

#define PORT_REQ    PORTD   // Define the PORT to REQ
#define PIN_REQ     6       // Define the PIN number to REQ
#define PORT_ACK    PORTC   // Define the PORT to ACK
#define PIN_ACK     5       // Define the PIN number to ACK

#define NUM_PARTITIONS  4          // Number of 32MB Prodos partions supported

#define LOG(str) do {         \
  Serial.print(micros());     \
  Serial.print(F("µs - "));   \
  Serial.println(str);        \
} while(0)

#define LOGN(str, num, enc) do {  \
  Serial.print(micros());         \
  Serial.print(F("µs - "));       \
  Serial.print(str);              \
  Serial.println(num, enc);       \
} while(0)

void encode_data_packet (unsigned char source);   //encode smartport 512 byte data packet
int  decode_data_packet (void);                   //decode smartport 512 byte data packet
void encode_write_status_packet(unsigned char source, unsigned char status);
void encode_init_reply_packet (unsigned char source, unsigned char status);
void encode_status_reply_packet (struct device d);
int  packet_length (void);
int partition;
bool is_valid_image(File imageFile);

extern "C" unsigned char ReceivePacket(unsigned char*); //Receive smartport packet assembler function
extern "C" unsigned char SendPacket(unsigned char*);    //send smartport packet assembler function

//unsigned char packet_buffer[768];   //smartport packet buffer
//unsigned char packet_buffer[605];   //smartport packet buffer
unsigned char *packet_buffer;         //Wing
//unsigned char sector_buffer[512];   //ata sector data buffer
unsigned char status, packet_byte;
int count;
int initPartition;

// We need to remember several things about a device, not just its ID
struct device{
  File sdf;
  unsigned char device_id;              //to hold assigned device id's for the partitions
  unsigned long blocks;                 //how many 512-byte blocks this image has
  unsigned int header_offset;           //Some image files have headers, skip this many bytes to avoid them
  //bool online;                          //Whether this image is currently available
                                          //No longer used, user devices[...].sdf.isOpen() instead
  bool writeable;
};

device devices[NUM_PARTITIONS];

//The circuit:
//    SD card attached to SPI bus as follows:
// ** MOSI - pin 11 on Arduino Uno/Duemilanove/Diecimila
// ** MISO - pin 12 on Arduino Uno/Duemilanove/Diecimila
// ** CLK - pin 13 on Arduino Uno/Duemilanove/Diecimila
// ** CS - depends on your SD card shield or module.
//     Pin 10 used here

// Change the value of chipSelect if your hardware does
// not use the default value, SS.  Common values are:
// Arduino Ethernet shield: pin 4
// Sparkfun SD shield: pin 8
// Adafruit SD shields and modules: pin 10

const uint8_t chipSelect = 10;
const uint8_t statusledPin = 18;

/*
   Set DISABLE_CHIP_SELECT to disable a second SPI device.
   For example, with the Ethernet shield, set DISABLE_CHIP_SELECT
   to 10 to disable the Ethernet controller.
*/
const int8_t DISABLE_CHIP_SELECT = 0;

SdFat sdcard;

//------------------------------------------------------------------------------


static void log_io_err(const __FlashStringHelper *op, int partition, int block_num) {
  Serial.print(op);
  Serial.print(F(" error on partition "));
  Serial.print((partition + initPartition) % NUM_PARTITIONS);
  Serial.print(F(", block "));
  Serial.println(block_num);
}

static int sd_init_done = 0;
static void late_init(void) {
  LOG(F("SmartportSD v1.18"));
  LOGN(F("Boot partition: "), initPartition, DEC);

  LOGN(F("Free memory before opening images: "), freeMemory(), DEC);

  // Not enough RAM for SDFat to open a file if the packet_buffer
  // is allocated.
  free(packet_buffer);

  if(!sd_init_done) {
    if (!sdcard.begin(chipSelect, SPI_HALF_SPEED)) {
      LOG(F("Error init card"));
      led_err();
    } else {
      sd_init_done = 1;
    }
  }

  SdFile myFile("config.txt", O_READ);
  // check for open error
  LOG(F("Opening partitions"));
  if (myFile.isOpen()) {
    unsigned char n;
    packet_buffer = (unsigned char *)malloc(100);
    for(unsigned char i = 0; i < NUM_PARTITIONS; i++){
      n = myFile.fgets((char*)packet_buffer, 100);
      if(n > 0) {
        if (packet_buffer[n - 1] == '\n') {
          packet_buffer[n-1] = 0;
        }
        LOG((char*)packet_buffer);

        open_image(devices[i],(char*)packet_buffer);
        if(!devices[i].sdf.isOpen()){
          LOG(F("Image open error!"));
        }
        else {
          if ((packet_buffer[n-4]=='2')&&((packet_buffer[n-3]&0xdf)=='M')&&((packet_buffer[n-2]&0xdf)=='G')) {
            devices[i].header_offset=64;
          }
          else {
            devices[i].header_offset=0;
          }
        }
      } else {
        if (initPartition > i) {
          LOG(F("Resetting boot partition to 0"));
          initPartition = 0;
        }
        break;
      }
    }

    free(packet_buffer);
    myFile.close();
  } else {
    Serial.println(F("No config.txt. Searching for images."));
    for (unsigned char i = 0; i < NUM_PARTITIONS; i++) {
      String prefix = "PART";
      open_image(devices[i], prefix+(i+1)+".po");
      if (!devices[i].sdf.isOpen()) {
        Serial.println(F("Can not open."));
      } else {
        Serial.println(F("Opened."));
      }
    }
  }
  LOGN(F("Free memory now "), freeMemory(), DEC);

  // Realloc standard packet_buffer
  packet_buffer = (unsigned char *)malloc(605);
}

void setup (void) {
  digitalWrite(statusledPin, HIGH);
  // Input/Output Ports initialization
  PORT_ACK = 0xFF;
  DDRC = 0xFF;

  PORTB = 0x00;

  PORT_REQ = _BV(7) | _BV(PIN_REQ);
  DDRD = 0x00;

  // Analog Comparator initialization
  ACSR = 0x80;

  // Serial init
  Serial.begin(230400);
  initPartition = eeprom_read_byte(0);
  if (initPartition == 0xFF) initPartition = 0;
  initPartition = (initPartition % NUM_PARTITIONS);

  packet_buffer = (unsigned char *)malloc(605);
  digitalWrite(statusledPin, LOW);
}

//*****************************************************************************
// Function: main loop
// Parameters: none
// Returns: 0
//
// Description: Main function for Apple //c Smartport Compact Flash adpater
//*****************************************************************************


void loop() {
  unsigned long int block_num;
  unsigned char LBH, LBL, LBN, LBT, LBX;

  int number_partitions_initialised = 0;
  bool sdstato;
  unsigned char source, status, phases, status_code;
  int not_mine = 0;

  DDRD = 0x00;

  // set RD low
  PORT_REQ &= ~(_BV(PIN_REQ));
  interrupts();

  LOG("Entering main loop");

  not_mine = 0;
  while (1) {
    DDRC = 0xDF; //set ack (wrprot) to input to avoid clashing with other devices when sp bus is not enabled

    // read phase lines to check for smartport reset or enable
    phases = (PIND & 0x3c) >> 2;

    switch (phases) {

      // phase lines for smartport bus reset
      // ph3=0 ph2=1 ph1=0 ph0=1

      case 0b00000101:
        LOG(F("SP BUS RESET"));

        // monitor phase lines for reset to clear
        while ((PIND & 0x3c) >> 2 == 0x05);

        //reset number of partitions init'd
        number_partitions_initialised = 0;

        not_mine = 0;

        //clear device_id table
        for (partition = 0; partition < NUM_PARTITIONS; partition++) {
          devices[partition].device_id = 0;
        }
        break;

      // phase lines for smartport bus enable
      // ph3=1 ph2=x ph1=1 ph0=x
      case 0b00001010:
      case 0b00001011:
      case 0b00001110:
      case 0b00001111:
        noInterrupts();
        DDRC = 0xFF;   //set ack to output, sp bus is enabled
        status = ReceivePacket( (unsigned char*) packet_buffer);
        interrupts();

        if (status) {
          break;     //error timeout, break and loop again
        }

        LOGN(F("SP BUS ENABLE, code "), packet_buffer[14], HEX);

        // lets check if the pkt is for us
        if (packet_buffer[14] != 0x85)  // if its an init pkt, then assume its for us and continue on
        {
          // check if its our one of our id's
          for  (partition = 0; partition < NUM_PARTITIONS; partition++)
          {
            if ( devices[(partition + initPartition) % NUM_PARTITIONS].device_id != packet_buffer[6])  //destination id
              not_mine++;
          }

          if (not_mine == NUM_PARTITIONS) { //not one of our id's
            delay(100);
            Serial.println(F("Not our ID!"));

            DDRC = 0xDF; //set ack to input, so lets not interfere
            PORT_ACK &= ~(_BV(PIN_ACK));   //set ack low, for next time its an output
            while (PINC & 0x20);  //wait till low other dev has finished receiving it

            //assume its a cmd packet, cmd code is in byte 14
            //now we need to work out what type of packet and stay out of the way
            switch (packet_buffer[14]) {
              case 0x80:  //is a status cmd
              case 0x83:  //is a format cmd
              case 0x81:  //is a readblock cmd
                while (!(PINC & 0x20));   //wait till high
                while (PINC & 0x20);      //wait till low
                while (!(PINC & 0x20));  //wait till high
                break;
              case 0x82:  //is a writeblock cmd
                while (!(PINC & 0x20));   //wait till high
                while (PINC & 0x20);      //wait till low
                while (!(PINC & 0x20));   //wait till high
                while (PINC & 0x20);      //wait till low
                while (!(PINC & 0x20));   //wait till high
                break;
            }
            break;  //not one of ours
          }
        }

        //else it is ours, we need to handshake the packet
        PORT_ACK &= ~(_BV(PIN_ACK));   //set ack low
        while (PIND & 0x04);   //wait for req to go low

        //Not safe to assume it's a normal command packet, GSOS may throw
        //us several extended packets here and then crash
        //Refuse an extended packet
        source = packet_buffer[6];

        //Check if its one of ours and an extended packet
        switch (packet_buffer[14]) {

          case 0x80:  //is a status cmd
            Serial.println(F("SP STATUS"));
            digitalWrite(statusledPin, HIGH);
            source = packet_buffer[6];
            for (partition = 0; partition < NUM_PARTITIONS; partition++) { //Check if its one of ours
              if (devices[(partition + initPartition) % NUM_PARTITIONS].device_id == source
                && devices[(partition + initPartition) % NUM_PARTITIONS].sdf.isOpen() ) {  //yes it is, and it's online, then reply

                status_code = (packet_buffer[19] & 0x7f);

                // if statcode=3, then status with device info block
                if (status_code == 0x03) {
                  Serial.println(F("Sending DIB"));
                  encode_status_dib_reply_packet(devices[(partition + initPartition) % NUM_PARTITIONS]);
                  delay(50);
                } else {
                  // just return device status
                  encode_status_reply_packet(devices[(partition + initPartition) % NUM_PARTITIONS]);
                }
                noInterrupts();
                DDRD = 0x40; //set rd as output
                status = SendPacket( (unsigned char*) packet_buffer);
                DDRD = 0x00; //set rd back to input so back to tristate
                interrupts();
                digitalWrite(statusledPin, LOW);
              }
            }
            break;


          case 0xC2:
            Serial.println(F("Extended write - Not implemented!"));
            break;
          case 0xC3:
            Serial.println(F("Extended format - Not implemented!"));
            break;
          case 0xC5:
            Serial.println(F("Extended init - Not implemented!"));
            break;

          case 0xC0:  //Extended status cmd
            digitalWrite(statusledPin, HIGH);
            source = packet_buffer[6];

            for (partition = 0; partition < NUM_PARTITIONS; partition++) { //Check if its one of ours
              if (devices[(partition + initPartition) % NUM_PARTITIONS].device_id == source) {
                //yes it is, then reply

                status_code = (packet_buffer[21] & 0x7f);
                LOGN(F("Extended Status CMD:"), status_code, HEX);
                print_packet ((unsigned char*) packet_buffer,packet_length());
                if (status_code == 0x03) { // if statcode=3, then status with device info block
                  Serial.println(F("Extended status DIB - Not implemented!"));
                } else {
                  // just return device status
                  encode_extended_status_reply_packet(devices[(partition + initPartition) % NUM_PARTITIONS]);
                }
                noInterrupts();
                DDRD = 0x40; //set rd as output
                status = SendPacket( (unsigned char*) packet_buffer);
                DDRD = 0x00; //set rd back to input so back to tristate
                interrupts();

              }
            }
            digitalWrite(statusledPin, LOW);
            break;

          case 0xC1:  // extended readblock cmd
          case 0x81:  // readblock cmd

            source = packet_buffer[6];

            LBH = packet_buffer[16]; //high order bits
            LBN = packet_buffer[19]; //block number low
            LBL = packet_buffer[20]; //block number middle
            LBT = packet_buffer[21]; //block number high

            for (partition = 0; partition < NUM_PARTITIONS; partition++) { //Check if its one of ours
              if (devices[(partition + initPartition) % NUM_PARTITIONS].device_id == source) {  //yes it is, then do the read
                // block num 1st byte
                block_num = (LBN & 0x7f) | (((unsigned short)LBH << 3) & 0x80);
                // block num second byte
                block_num = block_num + ( ((unsigned long)((LBL & 0x7f) | (((unsigned short)LBH << 4) & 0x80))) << 8);
                // block num third byte
                block_num = block_num + ( ((unsigned long)((LBT & 0x7f) | (((unsigned short)LBH << 5) & 0x80))) << 16);

                digitalWrite(statusledPin, HIGH);

                if(devices[(partition + initPartition) % NUM_PARTITIONS].sdf.isOpen()) {
                  if (!devices[(partition + initPartition) % NUM_PARTITIONS].sdf.seekSet(block_num*512+devices[(partition + initPartition) % NUM_PARTITIONS].header_offset)) {
                    log_io_err(F("Seek"), partition, block_num);
                  }
                }

                //Reading block from SD Card
                sdstato = devices[(partition + initPartition) % NUM_PARTITIONS].sdf.read((unsigned char*) packet_buffer, 512);
                if (!sdstato) {
                  log_io_err(F("Read"), partition, block_num);
                }
                encode_data_packet(source);

                noInterrupts();
                DDRD = 0x40; //set rd as output
                status = SendPacket( (unsigned char*) packet_buffer);
                DDRD = 0x00; //set rd back to input so back to tristate
                interrupts();
                digitalWrite(statusledPin, LOW);
              }
            }
            break;

          case 0x82:  //is a writeblock cmd
            source = packet_buffer[6];

            LBH = packet_buffer[16]; //high order bits
            LBN = packet_buffer[19]; //block number low
            LBL = packet_buffer[20]; //block number middle
            LBT = packet_buffer[21]; //block number high

            for (partition = 0; partition < NUM_PARTITIONS; partition++) { //Check if its one of ours
              if (devices[(partition + initPartition) % NUM_PARTITIONS].device_id == source) {  //yes it is, then do the write
                // block num 1st byte
                block_num = (LBN & 0x7f) | (((unsigned short)LBH << 3) & 0x80);
                // block num second byte
                block_num = block_num + ( ((unsigned long)((LBL & 0x7f) | (((unsigned short)LBH << 4) & 0x80))) << 8);
                // block num third byte
                block_num = block_num + ( ((unsigned long)((LBT & 0x7f) | (((unsigned short)LBH << 5) & 0x80))) << 16);

                //get write data packet, keep trying until no timeout
                noInterrupts();
                DDRC = 0xFF;   //set ack to output, sp bus is enabled
                while ((status = ReceivePacket( (unsigned char*) packet_buffer)));
                interrupts();

                //we need to handshake the packet
                PORT_ACK &= ~(_BV(PIN_ACK));   //set ack low
                while (PIND & 0x04);   //wait for req to go low

                status = decode_data_packet();
                if (status == 0) {
                  // ok
                  digitalWrite(statusledPin, HIGH);

                  if (!devices[(partition + initPartition) % NUM_PARTITIONS].sdf.seekSet(block_num*512+devices[(partition + initPartition) % NUM_PARTITIONS].header_offset)){
                    log_io_err(F("Seek"), partition, block_num);
                  }
                  // Write block to SD Card
                  sdstato = devices[(partition + initPartition) % NUM_PARTITIONS].sdf.write((unsigned char*) packet_buffer, 512);
                  if (!sdstato) {
                    log_io_err(F("Write"), partition, block_num);
                    status = 6;
                  }
                }
                //now return status code to host
                encode_write_status_packet(source, status);
                noInterrupts();
                DDRD = 0x40; //set rd as output
                status = SendPacket( (unsigned char*) packet_buffer);
                DDRD = 0x00; //set rd back to input so back to tristate
                interrupts();
              }
              digitalWrite(statusledPin, LOW);
            }
            break;

          case 0x83:  //is a format cmd
            source = packet_buffer[6];
            for (partition = 0; partition < NUM_PARTITIONS; partition++) { //Check if its one of ours
              if (devices[(partition + initPartition) % NUM_PARTITIONS].device_id == source) {  //yes it is, then reply to the format cmd
                encode_init_reply_packet(source, 0x80); //just send back a successful response
                noInterrupts();
                DDRD = 0x40; //set rd as output
                status = SendPacket( (unsigned char*) packet_buffer);
                interrupts();
                DDRD = 0x00; //set rd back to input so back to tristate
              }
            }
            break;

          case 0x85:  //is an init cmd
            source = packet_buffer[6];
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

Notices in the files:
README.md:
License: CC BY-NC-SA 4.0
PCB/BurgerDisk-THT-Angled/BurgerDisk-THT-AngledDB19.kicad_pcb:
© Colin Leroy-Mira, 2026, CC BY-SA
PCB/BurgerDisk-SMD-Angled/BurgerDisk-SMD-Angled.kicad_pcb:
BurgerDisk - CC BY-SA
